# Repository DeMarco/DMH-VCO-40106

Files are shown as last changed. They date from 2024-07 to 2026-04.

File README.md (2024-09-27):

# DMH-VCO-40106
 VCO module based on the design by Moritz Klein around a CD40106 Hex Inverter chip.
 I've modified the circuit considerably, but the essence is still the same:
  - Better CV processing:
      - Frequency modulation can now be attenuated completely when the amount knob is all the way CCW
      - Added trimpots to allow for fine frequency knob range adjustment and centering on a specific note (inspired by LMNC Performance VCO)
      - Added normalled connection to receive note CV directly from the Troley Bus power system
      - Added extra FM CV input (wanted to make it Linear FM instead of exponential, but gave up tryin to figure it out)
      - All CV inputs are now behind two stages of OpAmp based inverting amplifiers before hitting the transistor pair
      - Added trimpots to adjust PW knob range and symmetry, and adapted resistors to accept 100k potentiometer
  - Sync input added (so that the oscillator can be hard-synced to another)
  - Triangle wave shaper added (took from Moritz Klein Wave Folder circuit)
  - Sine wave shaper added (Thomas Henry design)
  - Tuner added (inspired by LMNC Performance VCO), my own design and firmware running on an ATtiny4313 (not Arduino)

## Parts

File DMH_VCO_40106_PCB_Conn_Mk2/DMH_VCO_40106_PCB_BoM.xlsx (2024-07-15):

Reference | Value | Footprint | Qty
C1,C2,C9 | 47uF | Capacitor_THT:CP_Radial_D4.0mm_P2.00mm | 3
C3,C4,C5,C6,C7,C8,C14 | 100nF | Capacitor_THT:C_Disc_D4.3mm_W1.9mm_P5.00mm | 7
C10 | 2.2nF |  | 1
C11,C13 | 1uF |  | 2
C12 | 2.2uF |  | 1
D1 | 1N4148 | Diode_THT:D_DO-35_SOD27_P7.62mm_Horizontal | 1
J1 | Sync | SynthStuff:CUI_MJ-63052A | 1
J2 | V/Oct | SynthStuff:CUI_MJ-63052A | 1
J3 | Exp FM | SynthStuff:CUI_MJ-63052A | 1
J4 | Lin FM | SynthStuff:CUI_MJ-63052A | 1
J5 | PW Mod | SynthStuff:CUI_MJ-63052A | 1
J6 | Senoid | SynthStuff:CUI_MJ-63052A | 1
J7 | Triangle | SynthStuff:CUI_MJ-63052A | 1
J8 | Square | SynthStuff:CUI_MJ-63052A | 1
J9 | Sawtooth | SynthStuff:CUI_MJ-63052A | 1
J10 | Panel_GND | Connector_PinHeader_2.54mm:PinHeader_1x01_P2.54mm_Vertical | 1
J100 | IDC_02x08 | SynthStuff:IDC-Header_2x08_P2.54mm_Vertical_Eurorack | 1
Q1 | BC558 | Package_TO_SOT_THT:TO-92_Inline | 1
Q2,Q3,Q4 | BC548 | Package_TO_SOT_THT:TO-92_Inline | 3
Q5,Q6 | 2N3904 | Package_TO_SOT_THT:TO-92_Inline | 2
R1,R3,R4,R6,R7,R8,R9,R12,R13,R17,R18,R25,R26,R27,RV1,RV2,RV6,RV9 | 100k | -- mixed values -- | 18
R2 | 33k | Resistor_THT:R_Axial_DIN0204_L3.6mm_D1.6mm_P5.08mm_Horizontal | 1
R5,R11,RV3,RV4 | 1M | -- mixed values -- | 4
R10 | 1k5 | Resistor_THT:R_Axial_DIN0204_L3.6mm_D1.6mm_P5.08mm_Horizontal | 1
R14,R19 | 68k | Resistor_THT:R_Axial_DIN0204_L3.6mm_D1.6mm_P5.08mm_Horizontal | 2
R15 | 14k | Resistor_THT:R_Axial_DIN0204_L3.6mm_D1.6mm_P5.08mm_Horizontal | 1
R16 | 47k | Resistor_THT:R_Axial_DIN0204_L3.6mm_D1.6mm_P5.08mm_Horizontal | 1
R20,R21,R24,R28,RV5 | 1k | -- mixed values -- | 5
R22,R23,R33,R34,R35,R36,RV8,TH1,TH2,TH3,TH4,TH5,TH6 | 10k | -- mixed values -- | 13
R29,R32 | 2k2 |  | 2
R30 | 390 |  | 1
R31 | 18k |  | 1
RV7 | 250k | Potentiometer_THT:Potentiometer_Alpha_RD901F-40-00D_Single_Vertical | 1
RV10 | 50k |  | 1
TP1,TP2,TP3,TP4,TP5,TP6 | TestPoint |  | 6
U1 | 40106 | Package_DIP:DIP-14_W7.62mm_Socket | 1
U2 | TL074 | Package_DIP:DIP-14_W7.62mm_Socket | 1
U3 | TL072 | -- mixed values -- | 1
JFET | bs170
ATTiny85
thermistors | 100K
thermistors | 10K
regulator | 7805
regulator | 7905
sockets

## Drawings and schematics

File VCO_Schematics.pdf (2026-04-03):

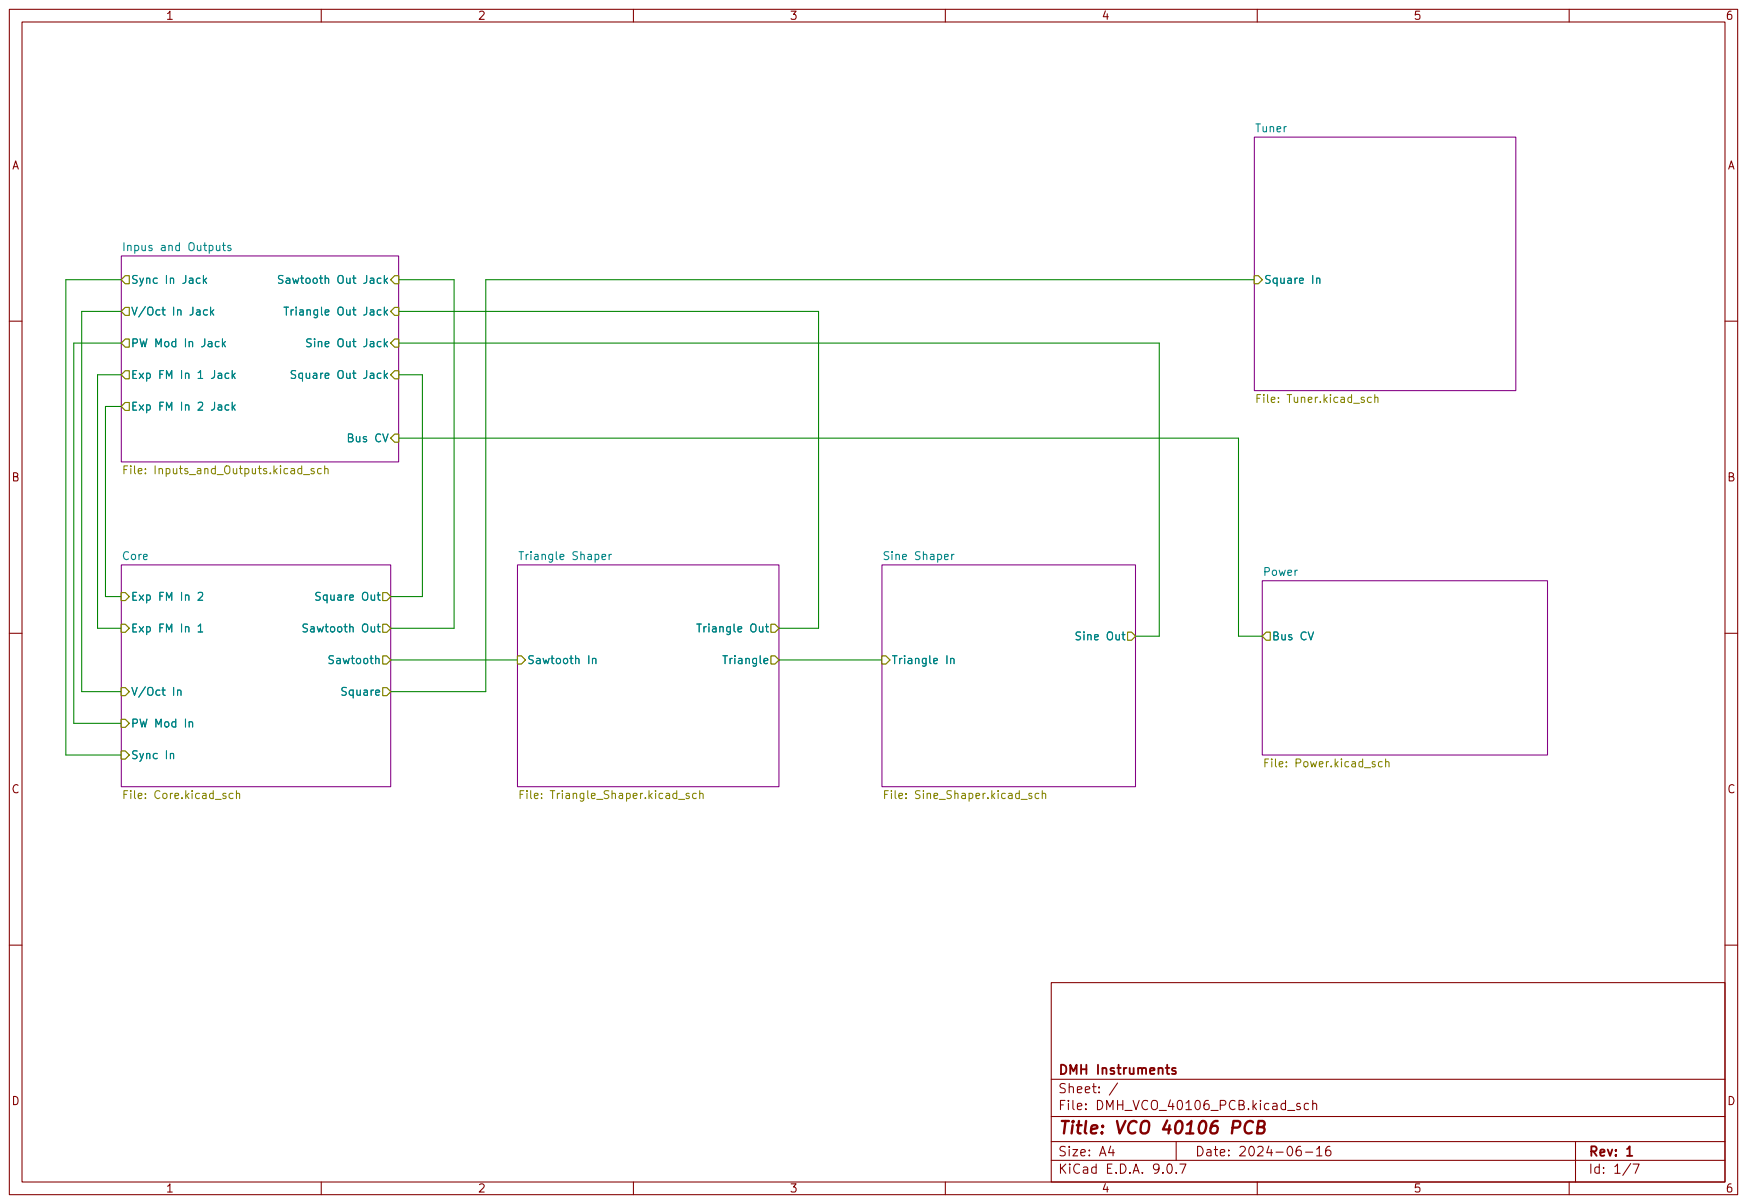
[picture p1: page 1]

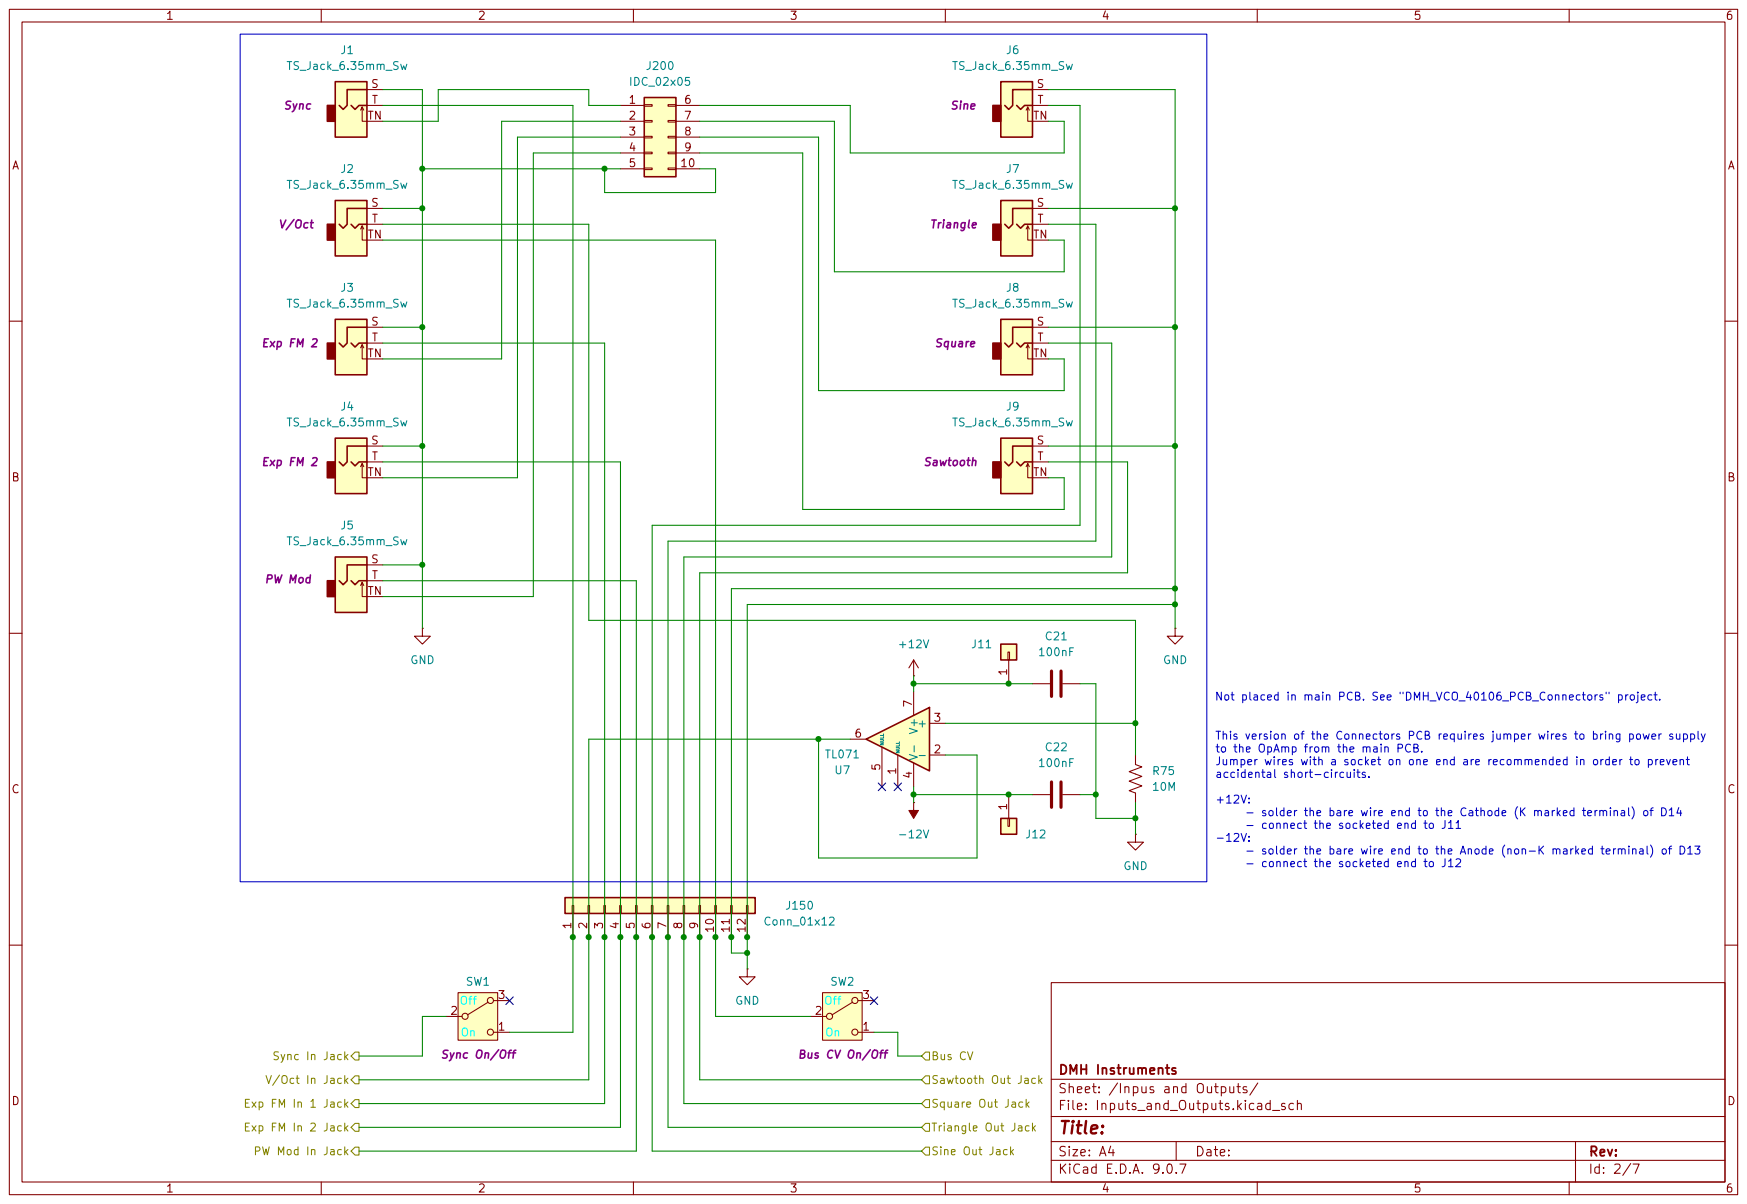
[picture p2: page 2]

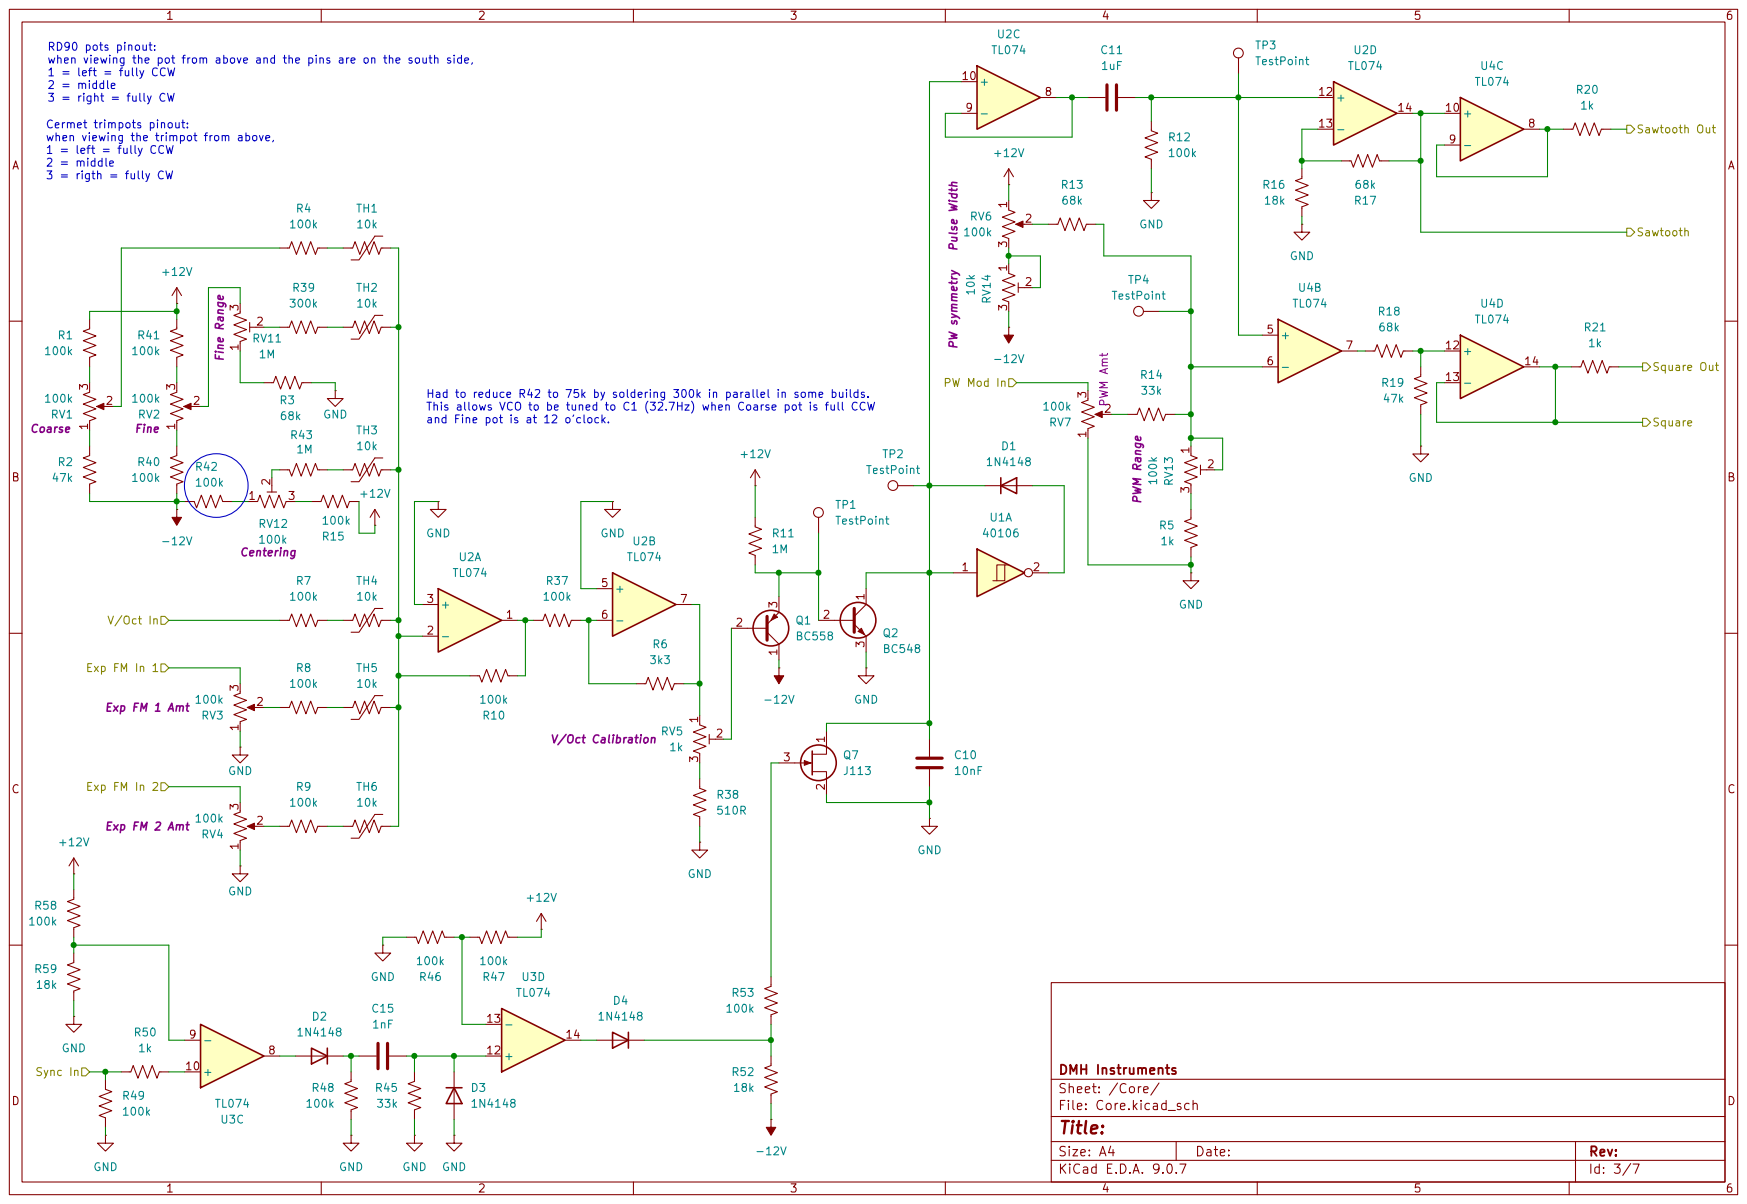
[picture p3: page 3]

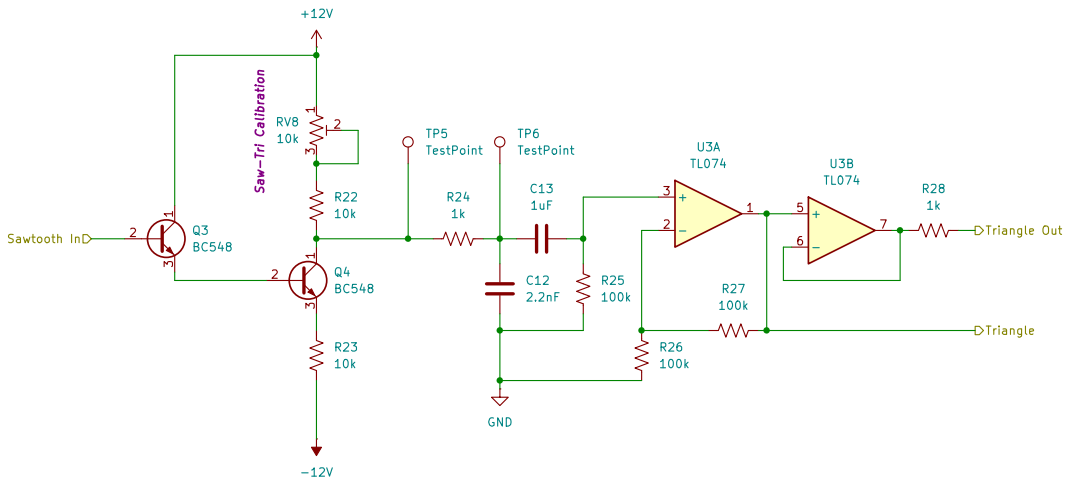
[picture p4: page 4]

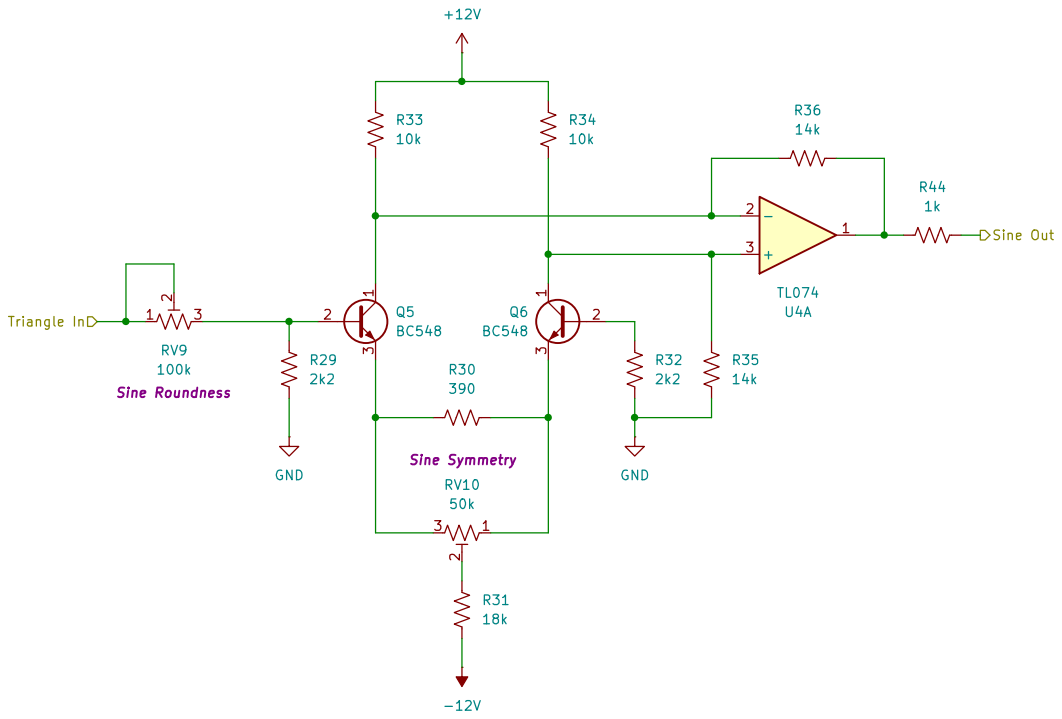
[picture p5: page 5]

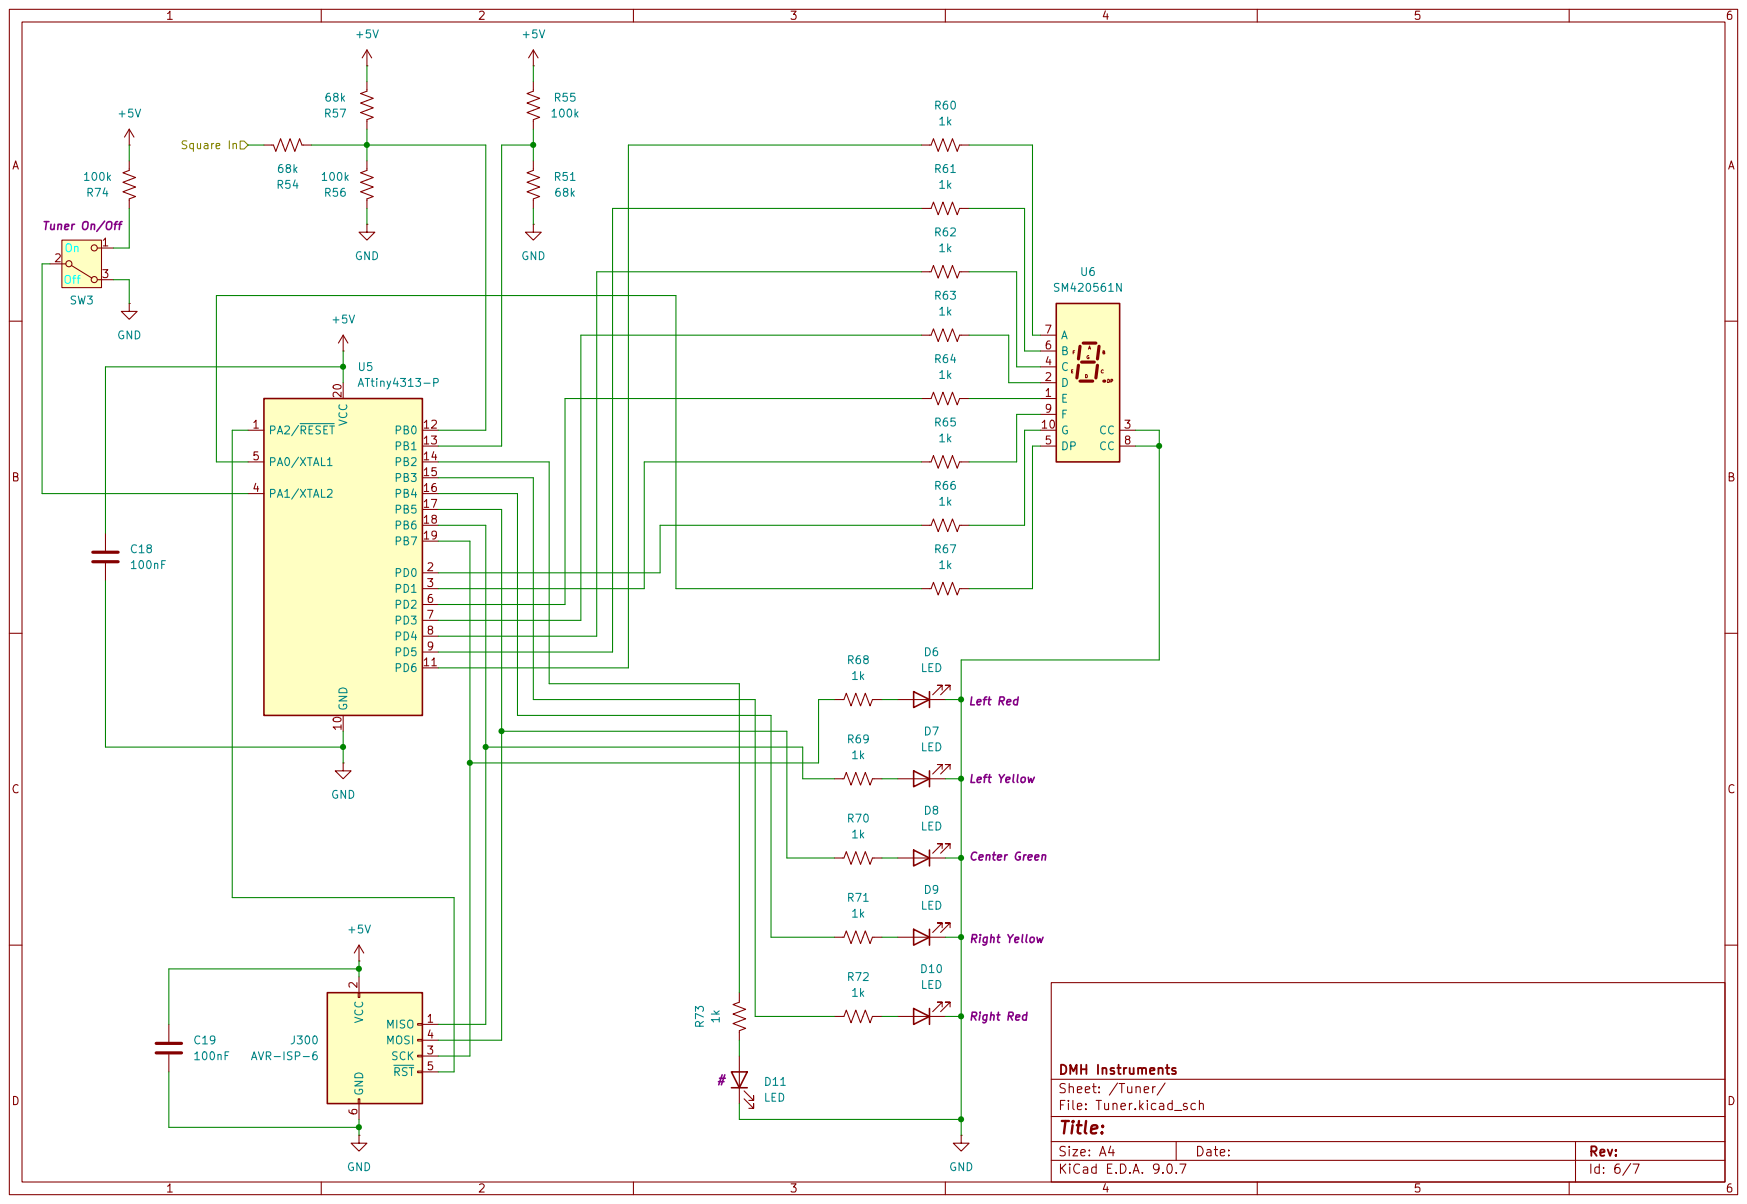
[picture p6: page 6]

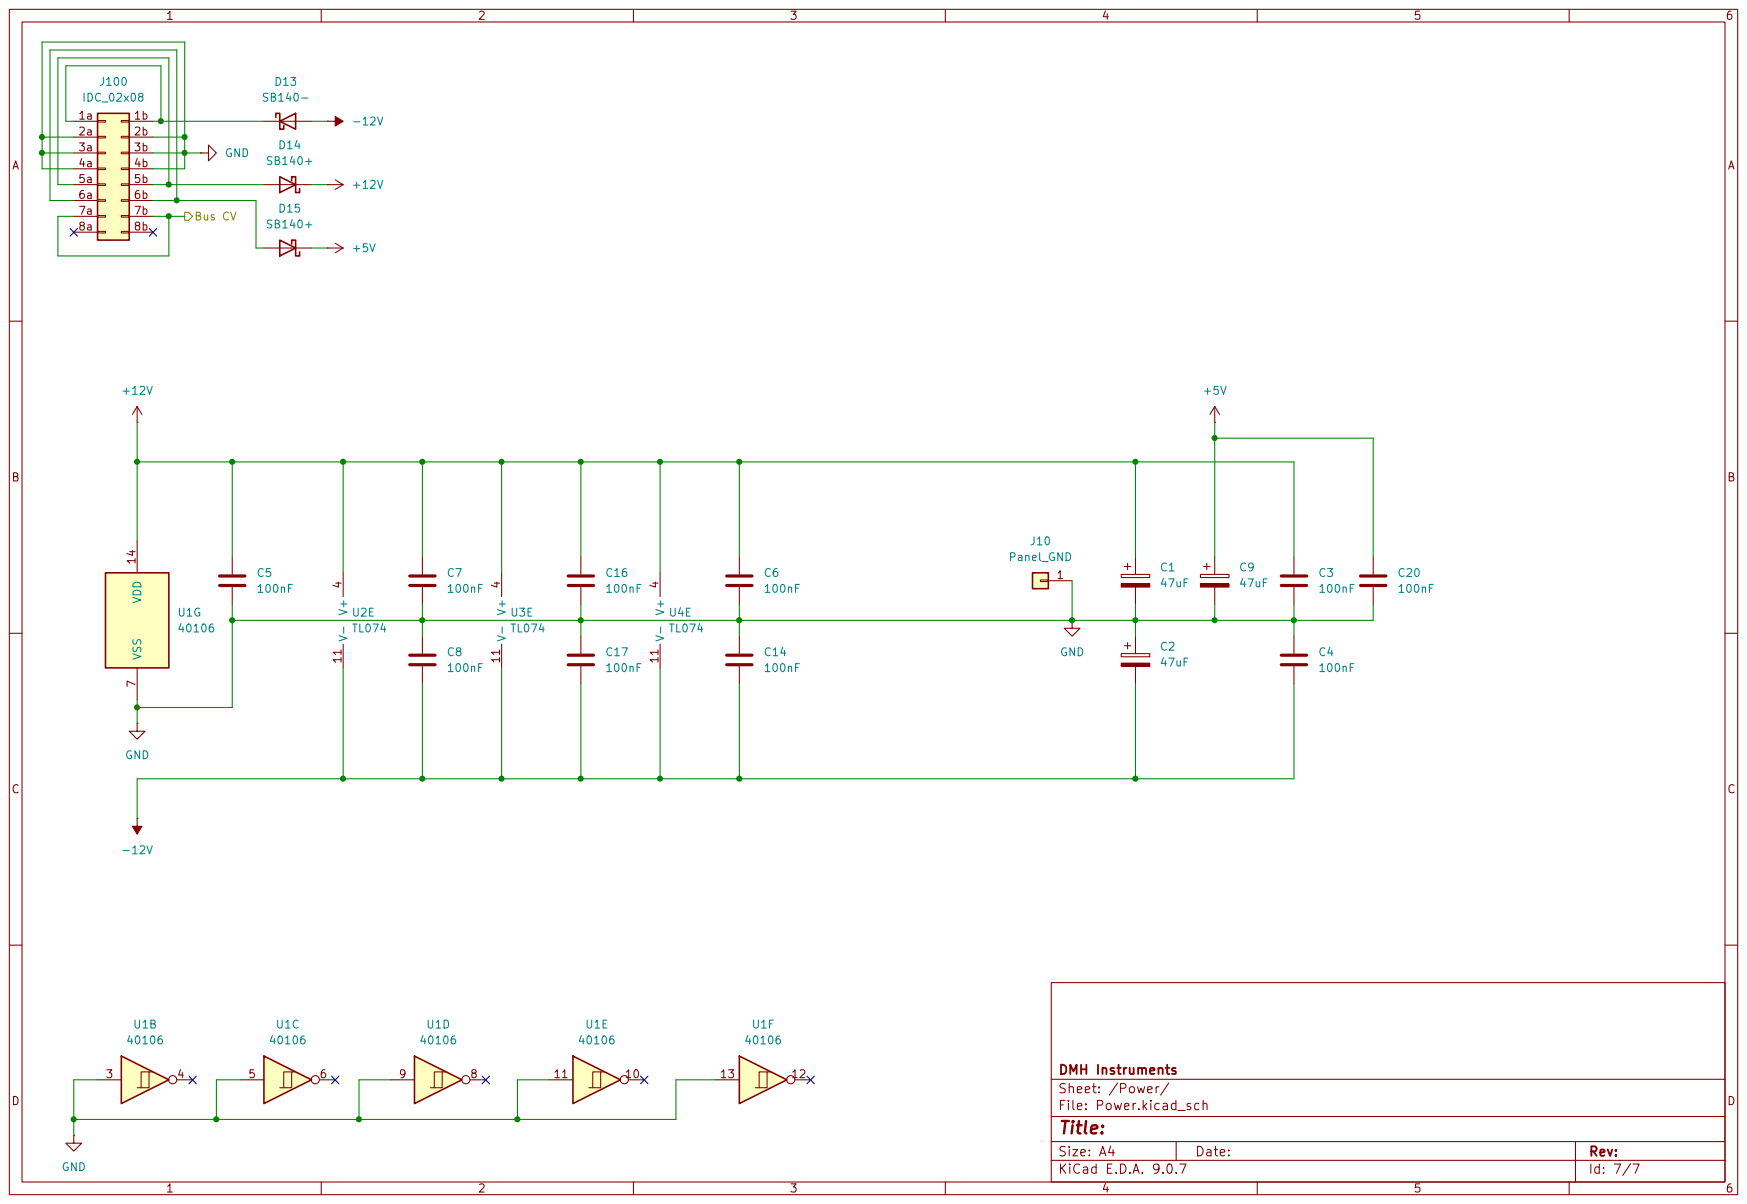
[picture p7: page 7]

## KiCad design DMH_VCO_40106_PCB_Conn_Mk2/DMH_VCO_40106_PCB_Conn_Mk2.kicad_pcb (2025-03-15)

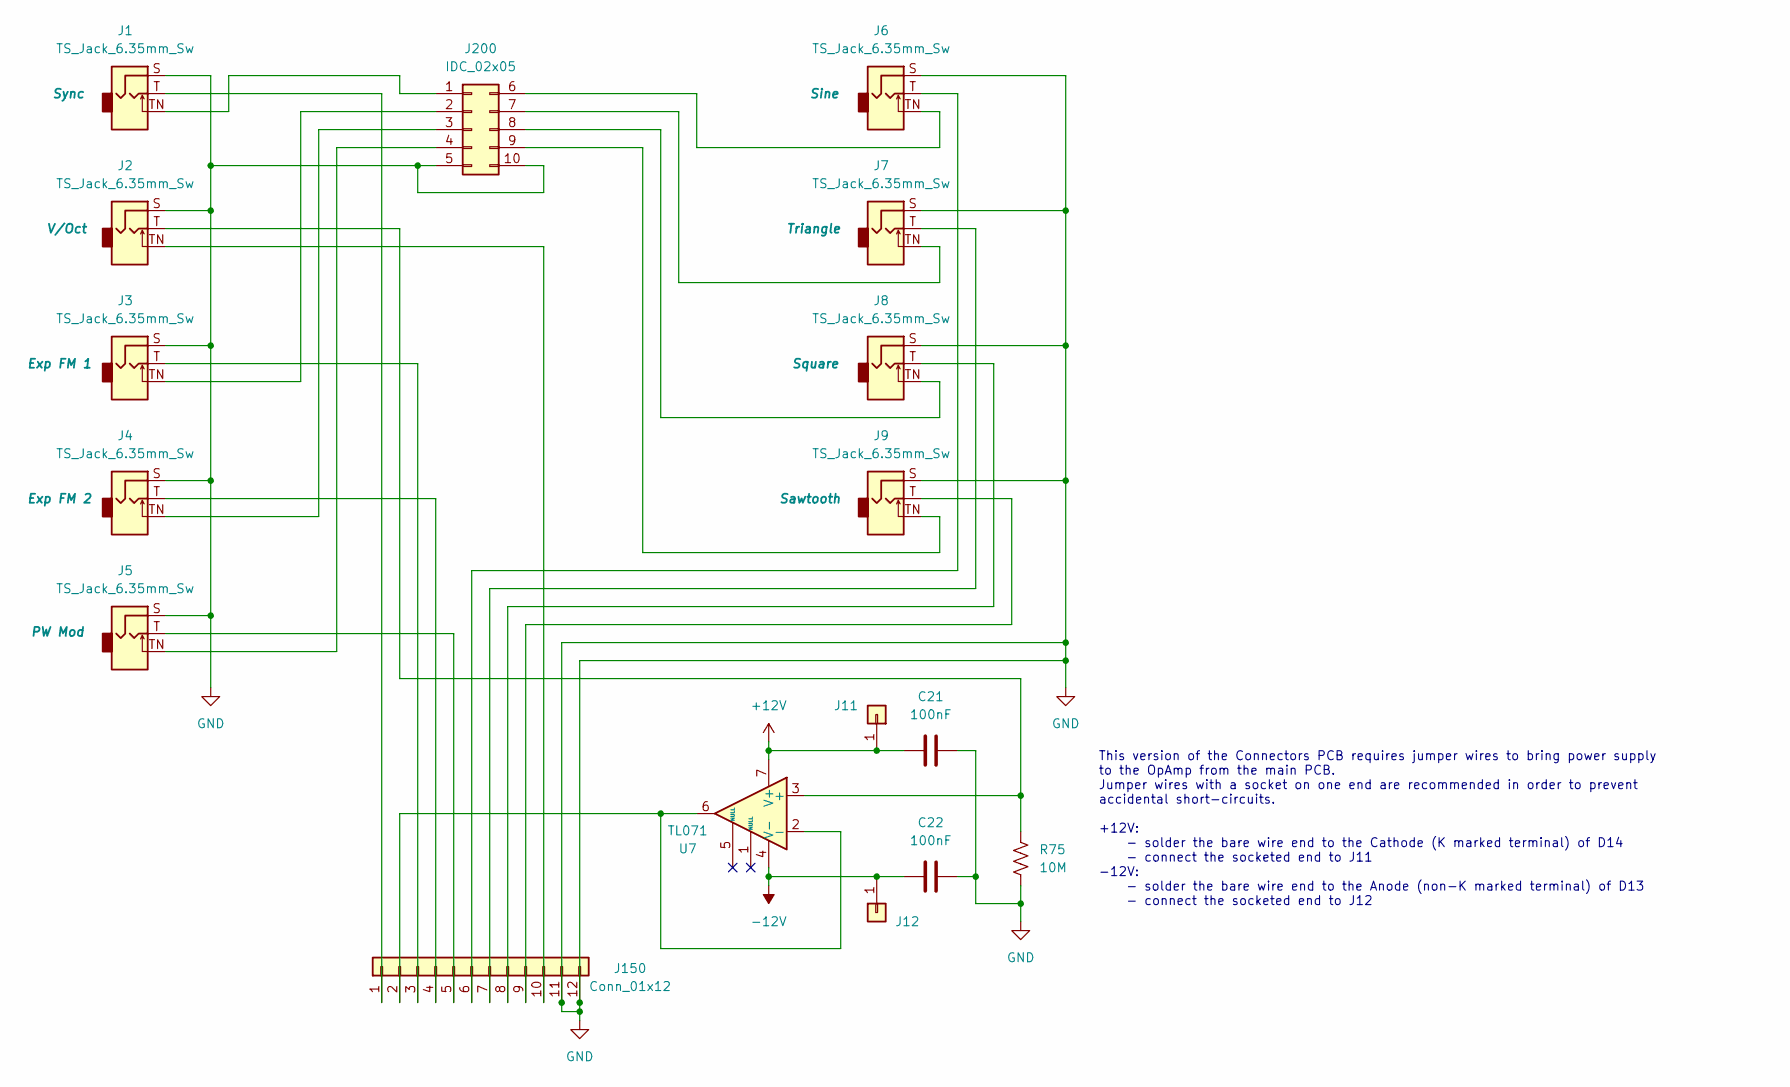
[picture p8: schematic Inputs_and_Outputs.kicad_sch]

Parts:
C21, C22: 100nF; C_Disc_D4.3mm_W1.9mm_P5.00mm
J1, J2, J3, J4, J5, J6, J7, J8, J9: TS_Jack_6.35mm_Sw; CUI_MJ-63052A
J11, J12: Conn_01x01; PinHeader_1x01_P2.54mm_Vertical
J150: Conn_01x12; PinHeader_1x12_P2.54mm_Vertical
J200: IDC_02x05; IDC-Header_2x05_P2.54mm_Vertical_BackBone
R75: 10M; R_Axial_DIN0207_L6.3mm_D2.5mm_P7.62mm_Horizontal
U7: TL071; DIP-8_W7.62mm_Socket

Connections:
+12V: C21.1, J11.1, U7.7 (V+)
-12V: C22.1, J12.1, U7.4 (V-)
GND: C21.2, C22.2, J1.S, J2.S, J3.S, J4.S, J5.S, J6.S, J7.S, J8.S, J9.S, J150.11, J150.12, J200.5, J200.10, R75.1
unnamed: J1.T, J150.1
unnamed: J150.2, U7.2 (-), U7.6
unnamed: J3.T, J150.3
unnamed: J4.T, J150.4
unnamed: J5.T, J150.5
unnamed: J6.T, J150.6
unnamed: J7.T, J150.7
unnamed: J8.T, J150.8
unnamed: J9.T, J150.9
unnamed: J2.TN, J150.10
unnamed: J1.TN, J200.1
unnamed: J3.TN, J200.2
unnamed: J4.TN, J200.3
unnamed: J5.TN, J200.4
unnamed: J6.TN, J200.6
unnamed: J7.TN, J200.7
unnamed: J8.TN, J200.8
unnamed: J9.TN, J200.9
unnamed: J2.T, R75.2, U7.3 (+)

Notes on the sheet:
This version of the Connectors PCB requires jumper wires to bring power supply to the OpAmp from the main PCB. Jumper wires with a socket on one end are recommended in order to prevent accidental short-circuits. +12V: - solder the bare wire end to the Cathode (K marked terminal) of D14 - connect th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

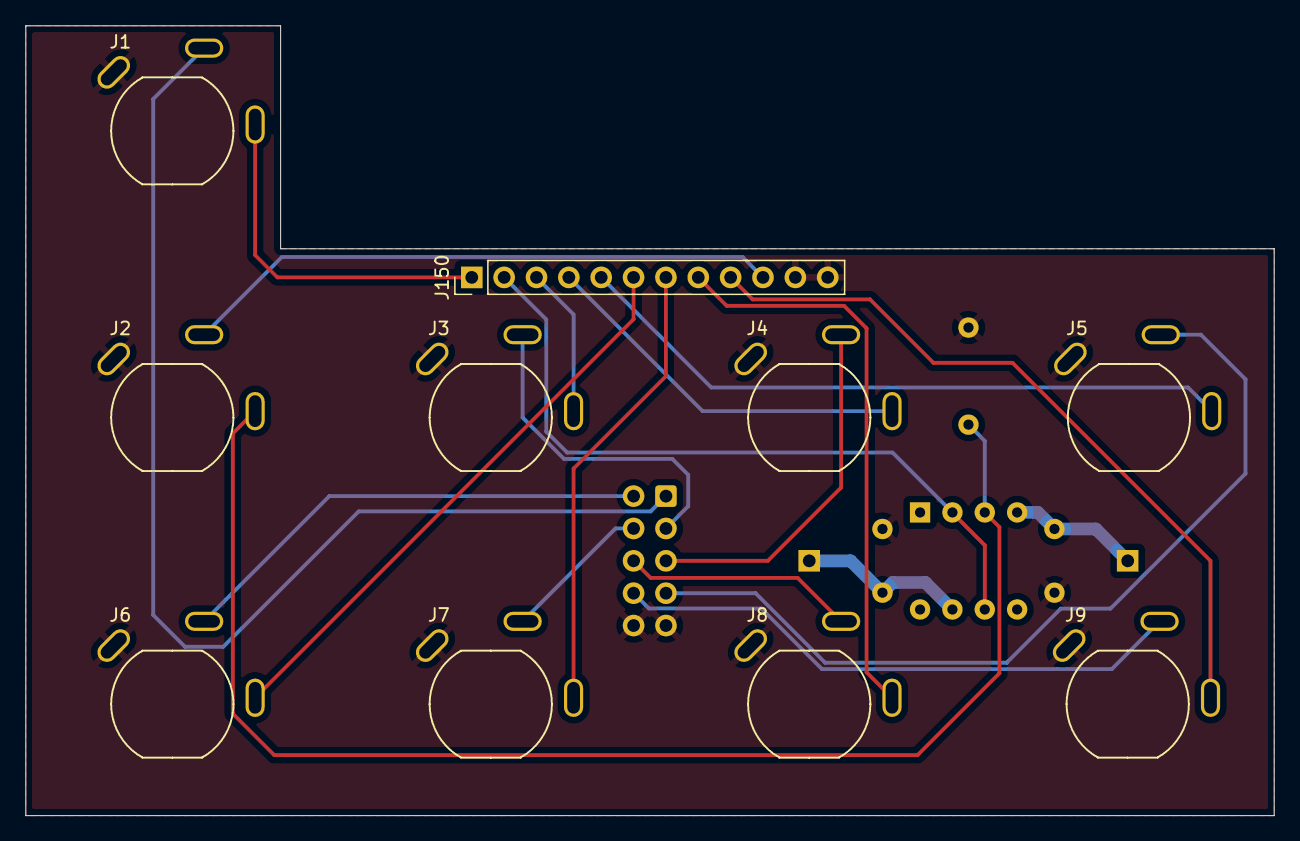
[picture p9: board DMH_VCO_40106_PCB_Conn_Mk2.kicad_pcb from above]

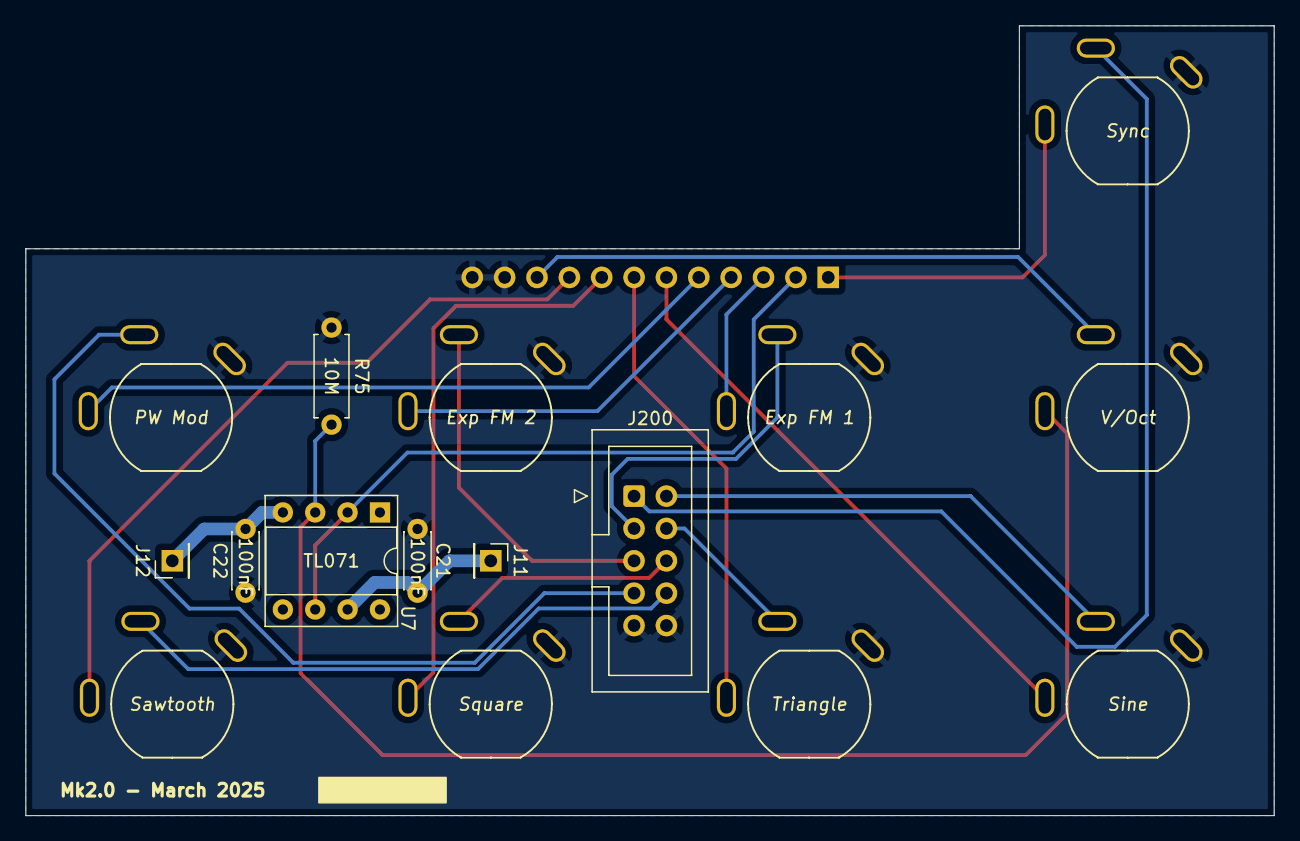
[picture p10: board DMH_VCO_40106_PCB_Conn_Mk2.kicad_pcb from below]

Board: 2 copper layers, 98.0 x 62.0 mm, 17 parts (7 on the bottom side), 22 nets.

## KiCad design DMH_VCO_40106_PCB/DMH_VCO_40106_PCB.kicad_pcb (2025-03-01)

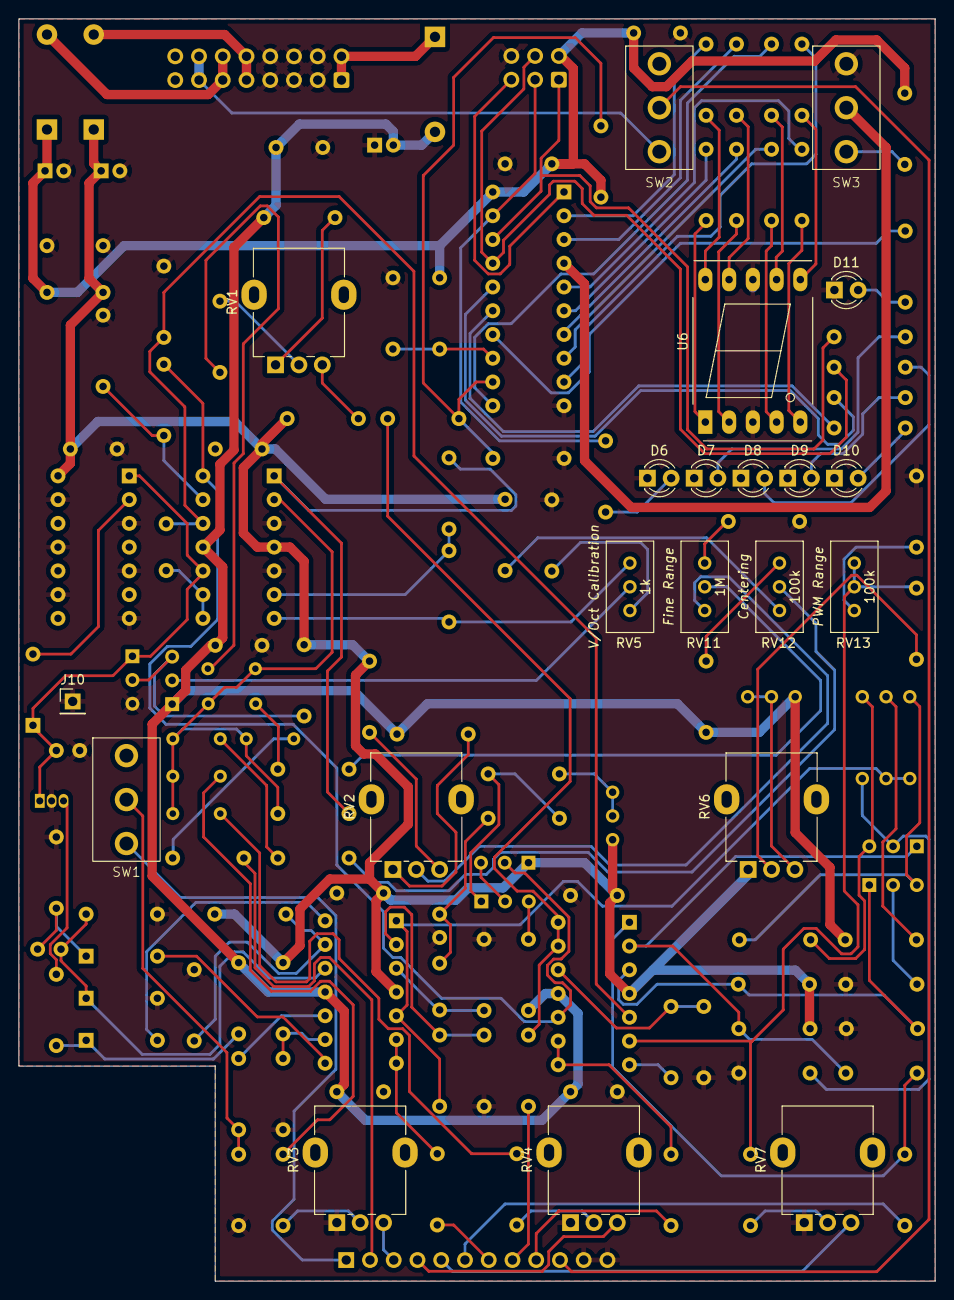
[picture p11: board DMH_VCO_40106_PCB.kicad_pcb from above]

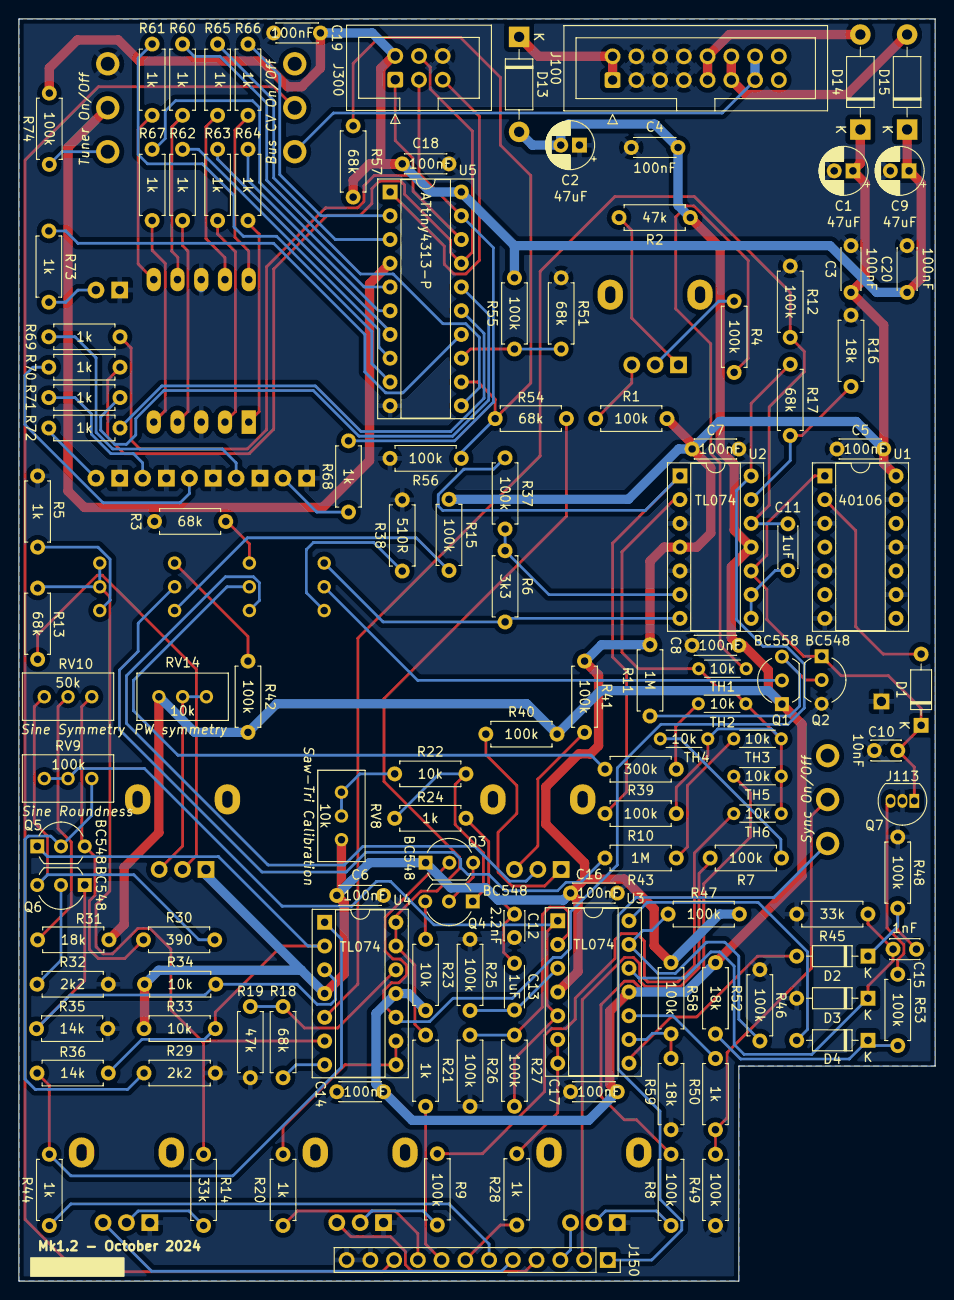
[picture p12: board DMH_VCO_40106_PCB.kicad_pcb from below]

Board: 2 copper layers, 98.0 x 135.0 mm, 147 parts (126 on the bottom side), 119 nets.

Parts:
C1, C2, C9: 47uF; CP_Radial_D5.0mm_P2.00mm
C3, C4, C5, C6, C7, C8, C14, C16, C17, C18, C19, C20: 100nF; C_Disc_D4.3mm_W1.9mm_P5.00mm
C10: 10nF; C_Disc_D3.0mm_W2.0mm_P2.50mm
C11, C13: 1uF; C_Disc_D4.3mm_W1.9mm_P5.00mm
C12: 2.2nF; C_Disc_D3.0mm_W2.0mm_P2.50mm
C15: 1nF; C_Disc_D3.0mm_W2.0mm_P2.50mm
D1, D2, D3, D4: 1N4148; D_DO-35_SOD27_P7.62mm_Horizontal
D6, D7, D8, D9, D10, D11: LED; LED_D3.0mm
D13: SB140-; D_DO-41_SOD81_P10.16mm_Horizontal
D14, D15: SB140+; D_DO-41_SOD81_P10.16mm_Horizontal
J10: Panel_GND; PinHeader_1x01_P2.54mm_Vertical
J100: IDC_02x08; IDC-Header_2x08_P2.54mm_Vertical_Eurorack
J150: Conn_01x12; PinSocket_1x12_P2.54mm_Vertical
J300: AVR-ISP-6; IDC-Header_2x03_P2.54mm_Vertical
Q1: BC558; TO-92_Inline_Wide
Q2, Q3, Q4, Q5, Q6: BC548; TO-92_Inline_Wide
Q7: J113; TO-92_Inline
R1, R4, R7, R8, R9, R10, R12, R15, R25, R26, R27, R37, R40, R41, R42, R46, R47, R48, R49, R53, R55, R56, R58, R74: 100k; R_Axial_DIN0207_L6.3mm_D2.5mm_P7.62mm_Horizontal
R2, R19: 47k; R_Axial_DIN0207_L6.3mm_D2.5mm_P7.62mm_Horizontal
R3, R13, R17, R18, R51, R54, R57: 68k; R_Axial_DIN0207_L6.3mm_D2.5mm_P7.62mm_Horizontal
R5, R20, R21, R24, R28, R44, R50, R60, R61, R62, R63, R64, R65, R66, R67, R68, R69, R70, R71, R72, R73: 1k; R_Axial_DIN0207_L6.3mm_D2.5mm_P7.62mm_Horizontal
R6: 3k3; R_Axial_DIN0207_L6.3mm_D2.5mm_P7.62mm_Horizontal
R11, R43: 1M; R_Axial_DIN0207_L6.3mm_D2.5mm_P7.62mm_Horizontal
R14, R45: 33k; R_Axial_DIN0207_L6.3mm_D2.5mm_P7.62mm_Horizontal
R16, R31, R52, R59: 18k; R_Axial_DIN0207_L6.3mm_D2.5mm_P7.62mm_Horizontal
R22, R23, R33, R34: 10k; R_Axial_DIN0207_L6.3mm_D2.5mm_P7.62mm_Horizontal
R29, R32: 2k2; R_Axial_DIN0207_L6.3mm_D2.5mm_P7.62mm_Horizontal
R30: 390; R_Axial_DIN0207_L6.3mm_D2.5mm_P7.62mm_Horizontal
R35, R36: 14k; R_Axial_DIN0207_L6.3mm_D2.5mm_P7.62mm_Horizontal
R38: 510R; R_Axial_DIN0207_L6.3mm_D2.5mm_P7.62mm_Horizontal
R39: 300k; R_Axial_DIN0207_L6.3mm_D2.5mm_P7.62mm_Horizontal
RV1, RV2, RV3, RV4, RV6, RV7: 100k; Potentiometer_Alpha_RD901F-40-00D_Single_Vertical
RV5: 1k; Potentiometer_Bourns_3296W_Vertical
RV8, RV14: 10k; Potentiometer_Bourns_3296W_Vertical
RV9, RV12, RV13: 100k; Potentiometer_Bourns_3296W_Vertical
RV10: 50k; Potentiometer_Bourns_3296W_Vertical
RV11: 1M; Potentiometer_Bourns_3296W_Vertical
SW1, SW2, SW3: SW_SPDT_321_OnOff; Toggle_Switch_THT
TH1, TH2, TH3, TH4, TH5, TH6: 10k; R_Axial_DIN0204_L3.6mm_D1.6mm_P5.08mm_Horizontal
U1: 40106; DIP-14_W7.62mm_Socket
U2, U3, U4: TL074; DIP-14_W7.62mm_Socket
U5: ATtiny4313-P; DIP-20_W7.62mm_Socket
U6: SM420561N; 7SegmentLED_LTS6760_LTS6780

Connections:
+5V: C9.1, C18.1, C19.1, C20.1, D15.1 (K), J300.2 (VCC), R55.2, R57.1, R74.1, U5.20 (VCC)
+12V: C1.1, C3.1, C5.1, C6.1, C7.1, C16.1, D14.1 (K), Q3.1 (C), R1.2, R11.2, R15.1, R33.1, R34.1, R41.1, R47.2, R58.1, RV6.1, RV8.1, U1.14 (VDD), U2.4 (V+), U3.4 (V+), U4.4 (V+)
-12V: C2.2, C4.2, C8.2, C14.2, C17.2, D13.2 (A), Q1.1 (C), R2.1, R23.2, R31.1, R40.2, R42.2, R52.2, RV14.3, U2.11 (V-), U3.11 (V-), U4.11 (V-)
/Core/Exp FM In 1: J150.3, RV3.3
/Core/Exp FM In 2: J150.4, RV4.3
/Core/PW Mod In: J150.5, RV7.3
/Core/Sawtooth: Q3.2 (B), R17.1, U2.14, U4.10 (+)
/Core/Sawtooth Out: J150.9, R20.2
/Core/Square: R21.1, R54.1, U4.13 (-), U4.14
/Core/Square Out: J150.8, R21.2
/Core/Sync In: R49.2, R50.2, SW1.2 (B)
/Core/V/Oct In: J150.2, R7.2
/Inpus and Outputs/Bus CV: J100.7a, J100.7b, SW2.1 (C)
/Inpus and Outputs/Sine Out Jack: J150.6, R44.1
/Inpus and Outputs/Triangle Out Jack: J150.7, R28.1
/Sine Shaper/Triangle In: R27.2, RV9.1, RV9.2, U3.1, U3.5 (+)
GND: C1.2, C2.1, C3.2, C4.1, C5.2, C6.2, C7.2, C8.1, C9.2, C10.2, C12.1, C14.1, C16.2, C17.1, C18.2, C19.2, C20.2, D3.2 (A), D6.1 (K), D7.1 (K), D8.1 (K), D9.1 (K), D10.1 (K), D11.1 (K), J10.1, J100.2a, J100.2b, J100.3a, J100.3b, J100.4a, J100.4b, J150.11, J150.12, J300.6 (GND), Q2.3 (E), Q7.2 (S), R3.1, R5.2, R12.1, R16.1, R19.2, R25.2, R26.2, R29.2, R32.2, R35.2, R38.2, R45.2, R46.1, R48.2, R49.1, R51.1, R56.2, R59.2, RV3.1, RV4.1, RV7.1, SW3.3 (A), U1.3, U1.5, U1.7 (VSS), U1.9, U1.11, U1.13, U2.3 (+), U2.5 (+), U5.10 (GND), U6.3 (CC), U6.8 (CC)
unnamed: C12.2, C13.1, R24.2
unnamed: D1.2 (A), U1.2
unnamed: C10.1, D1.1 (K), Q2.1 (C), Q7.1 (D), U1.1, U2.10 (+)
unnamed: D2.2 (A), U3.8
unnamed: C15.1, D2.1 (K), R48.1
unnamed: C15.2, D3.1 (K), R45.1, U3.12 (+)
unnamed: D4.2 (A), U3.14
unnamed: D4.1 (K), R52.1, R53.2
unnamed: D6.2 (A), R68.2
unnamed: D7.2 (A), R69.2
unnamed: D8.2 (A), R70.2
unnamed: D9.2 (A), R71.2
unnamed: D10.2 (A), R72.2
unnamed: D11.2 (A), R73.2
unnamed: D13.1 (K), J100.1a, J100.1b
unnamed: D14.2 (A), J100.5a, J100.5b
unnamed: D15.2 (A), J100.6a, J100.6b
unnamed: J150.1, SW1.1 (C)
unnamed: J150.10, SW2.2 (B)
unnamed: J300.1 (MISO), R69.1, U5.18 (PB6)
unnamed: J300.4 (MOSI), R70.1, U5.17 (PB5)
unnamed: J300.3 (SCK), R68.1, U5.19 (PB7)
unnamed: J300.5 (~RST), U5.1 (PA2/~RESET)
unnamed: Q1.2 (B), RV5.2
unnamed: Q1.3 (E), Q2.2 (B), R11.1
unnamed: Q3.3 (E), Q4.2 (B)
unnamed: Q4.1 (C), R22.2, R24.1
unnamed: Q4.3 (E), R23.1
unnamed: Q5.2 (B), R29.1, RV9.3
unnamed: Q5.1 (C), R33.2, R36.1, U4.2 (-)
unnamed: Q5.3 (E), R30.1, RV10.3
unnamed: Q6.2 (B), R32.1
unnamed: Q6.1 (C), R34.2, R35.1, U4.3 (+)
unnamed: Q6.3 (E), R30.2, RV10.1
unnamed: Q7.3 (G), R53.1
unnamed: R1.1, RV1.3
unnamed: R2.2, RV1.1
unnamed: R3.2, RV11.1
unnamed: R4.1, RV1.2
unnamed: R4.2, TH1.1
unnamed: R5.1, RV13.3
unnamed: R6.2, RV5.1, U2.7
unnamed: R7.1, TH4.1
unnamed: R8.1, RV3.2
unnamed: R8.2, TH5.1
unnamed: R9.1, RV4.2
unnamed: R9.2, TH6.1
unnamed: R10.2, R37.1, U2.1
unnamed: R13.2, RV6.2
unnamed: R14.2, RV7.2
unnamed: R15.2, RV12.3
unnamed: R18.2, U4.7
unnamed: R22.1, RV8.2, RV8.3
unnamed: R31.2, RV10.2
unnamed: R36.2, R44.2, U4.1
unnamed: R38.1, RV5.3
unnamed: R39.1, RV11.2
unnamed: R39.2, TH2.1
unnamed: R40.1, RV2.1
unnamed: R41.2, RV2.3
unnamed: R42.1, RV12.1
unnamed: R43.1, TH3.1
unnamed: R43.2, RV12.2
unnamed: RV2.2, RV11.3
unnamed: RV6.3, RV14.1, RV14.2
unnamed: SW3.2 (B), U5.4 (PA1/XTAL2)
unnamed: R74.2, SW3.1 (C)
unnamed: R10.1, TH1.2, TH2.2, TH3.2, TH4.2, TH5.2, TH6.2, U2.2 (-)
unnamed: R6.1, R37.2, U2.6 (-)
unnamed: C11.1, U2.8, U2.9 (-)
unnamed: C11.2, R12.2, U2.12 (+), U4.5 (+)
unnamed: R16.2, R17.2, U2.13 (-)
unnamed: C13.2, R25.1, U3.3 (+)
unnamed: R26.1, R27.1, U3.2 (-)
unnamed: R28.2, U3.6 (-), U3.7
unnamed: R50.1, U3.10 (+)
unnamed: R58.2, R59.1, U3.9 (-)
unnamed: R46.2, R47.1, U3.13 (-)
unnamed: R13.1, R14.1, RV13.1, RV13.2, U4.6 (-)
unnamed: R20.1, U4.8, U4.9 (-)
unnamed: R18.1, R19.1, U4.12 (+)
unnamed: R67.1, U5.5 (PA0/XTAL1)
unnamed: R54.2, R56.1, R57.2, U5.12 (PB0)
unnamed: R51.2, R55.1, U5.13 (PB1)
unnamed: R73.1, U5.14 (PB2)
unnamed: R72.1, U5.15 (PB3)
unnamed: R71.1, U5.16 (PB4)
unnamed: R66.1, U5.2 (PD0)
unnamed: R65.1, U5.3 (PD1)
unnamed: R64.1, U5.6 (PD2)
unnamed: R63.1, U5.7 (PD3)
unnamed: R62.1, U5.8 (PD4)
unnamed: R61.1, U5.9 (PD5)
unnamed: R60.1, U5.11 (PD6)
unnamed: R60.2, U6.7 (A)
unnamed: R61.2, U6.6 (B)
unnamed: R62.2, U6.4 (C)
unnamed: R63.2, U6.2 (D)
unnamed: R67.2, U6.5 (DP)
unnamed: R64.2, U6.1 (E)
unnamed: R65.2, U6.9 (F)
unnamed: R66.2, U6.10 (G)

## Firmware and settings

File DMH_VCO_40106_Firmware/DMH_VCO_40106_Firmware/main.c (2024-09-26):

/*
 * DMH_VCO_40106_Firmware.c
 *
 * Created: 25/08/2024 20:57:13
 * Author : Draycon
 */ 

#include "definitions.h"
#include <inttypes.h>
#include <stdio.h>
#include <stdlib.h>
#include <avr/io.h>
#include <avr/interrupt.h>
#include <avr/pgmspace.h>
#include <util/delay.h>
#include <avr/eeprom.h>
#include "Frequency_table_float.h"

//////// GLOBAL VARIABLES ////////

uint16_t event_timestamp = 0;


/////// FUNCTIONS /////////

/*
Show that the 7 segments display and LEDs are all working at power up.
*/
void init_display (void)
{
	// Switch off all segments
	PORTA &= ~_BV(SEG_DP);
	ALL_SEGS_OFF();
	
	// Light up all segments and LEDs in order
	_delay_ms(150);
	PORTD |= _BV(SEG_F);
	_delay_ms(150);
	PORTD |= _BV(SEG_A);
	_delay_ms(150);
	PORTD |= _BV(SEG_B);
	_delay_ms(150);
	PORTD |= _BV(SEG_C);
	_delay_ms(150);
	PORTD |= _BV(SEG_D);
	_delay_ms(150);
	PORTD |= _BV(SEG_E);
	_delay_ms(150);
	PORTD |= _BV(SEG_G);
	_delay_ms(150);
	PORTA |= _BV(SEG_DP);
	_delay_ms(150);
	LED_Sharp_ON();
	_delay_ms(150);
	LED_L_Red_ON();
	_delay_ms(150);
	LED_L_Yellow_ON();
	_delay_ms(150);
	LED_C_Green_ON();
	_delay_ms(150);
	LED_R_Yellow_ON();
	_delay_ms(150);
	LED_R_Red_ON();
	_delay_ms(1000);
	// Switch off all segments
	ALL_SEGS_OFF();
	// Switch off all LEDs
	ALL_LEDS_OFF();
}

/*
Light up the 7 segments display and "sharp" LED according to the calculated note.
*/
void display_note (uint8_t note)
{
	switch(note)
	{
		case NOTE_C:
			//PORTD = _BV(SEG_A) | _BV(SEG_D) | _BV(SEG_E) | _BV(SEG_F) & ~_BV(SEG_B) & ~_BV(SEG_C) & ~_BV(SEG_G);
			PORTD = 0x4E;
			LED_Sharp_OFF();
			break;
			
		case NOTE_Cs:
			//PORTD = _BV(SEG_A) | _BV(SEG_D) | _BV(SEG_E) | _BV(SEG_F) & ~_BV(SEG_B) & ~_BV(SEG_C) & ~_BV(SEG_G);
			PORTD = 0x4E;
			LED_Sharp_ON();
			break;
			
		case NOTE_D:
			//PORTD = _BV(SEG_B) | _BV(SEG_C) | _BV(SEG_D) | _BV(SEG_E) | _BV(SEG_G) & ~_BV(SEG_A) & ~_BV(SEG_F);
			PORTD = 0x3D;
			LED_Sharp_OFF();
			break;
			
		case NOTE_Ds:
			//PORTD = _BV(SEG_B) | _BV(SEG_C) | _BV(SEG_D) | _BV(SEG_E) | _BV(SEG_G) & ~_BV(SEG_A) & ~_BV(SEG_F);
			PORTD = 0x3D;
			LED_Sharp_ON();
			break;
			
		case NOTE_E:
			//PORTD = _BV(SEG_A) | _BV(SEG_D) | _BV(SEG_E) | _BV(SEG_F) | _BV(SEG_G) & ~_BV(SEG_B) & ~_BV(SEG_C);
			PORTD = 0x4F;
			LED_Sharp_OFF();
			break;
		
		case NOTE_F:
			//PORTD = _BV(SEG_A) | _BV(SEG_E) | _BV(SEG_F) | _BV(SEG_G) & ~_BV(SEG_B) & ~_BV(SEG_C) & ~_BV(SEG_D);
			PORTD = 0x47;
			LED_Sharp_OFF();
			break;
			
		case NOTE_Fs:
			//PORTD = _BV(SEG_A) | _BV(SEG_E) | _BV(SEG_F) | _BV(SEG_G) & ~_BV(SEG_B) & ~_BV(SEG_C) & ~_BV(SEG_D);
			PORTD = 0x47;
			LED_Sharp_ON();
			break;
				
		case NOTE_G:
			//PORTD = _BV(SEG_A) | _BV(SEG_C) | _BV(SEG_D) | _BV(SEG_E) | _BV(SEG_F) & ~_BV(SEG_G) & ~_BV(SEG_B);
			PORTD = 0x5E;
			LED_Sharp_OFF();
			break;
			
		case NOTE_Gs:
			//PORTD = _BV(SEG_A) | _BV(SEG_C) | _BV(SEG_D) | _BV(SEG_E) | _BV(SEG_F) & ~_BV(SEG_G) & ~_BV(SEG_B);
			PORTD = 0x5E;
			LED_Sharp_ON();
			break;
			
		case NOTE_A:
			//PORTD = _BV(SEG_A) | _BV(SEG_B) | _BV(SEG_C) | _BV(SEG_E) | _BV(SEG_F) | _BV(SEG_G) & ~_BV(SEG_D);
			PORTD = 0x77;
			LED_Sharp_OFF();
			break;
			
		case NOTE_As:
			//PORTD = _BV(SEG_A) | _BV(SEG_B) | _BV(SEG_C) | _BV(SEG_E) | _BV(SEG_F) | _BV(SEG_G) & ~_BV(SEG_D);
			PORTD = 0x77;
			LED_Sharp_ON();
			break;
			
		case NOTE_B:
			//PORTD = _BV(SEG_C) | _BV(SEG_D) | _BV(SEG_E) | _BV(SEG_F) | _BV(SEG_G) & ~_BV(SEG_A) & ~_BV(SEG_B);
			PORTD = 0x1F;
			LED_Sharp_OFF();
			break;
			
		case NOTE_TOO_LOW:
			// Seg D only
			PORTD = 0x08;
			LED_Sharp_OFF();
			break;
		
		case NOTE_TOO_HIGH:
			// Seg A only
			PORTD = 0x40;
			LED_Sharp_OFF();
			break;
		
		default:
			// Seg A and B, diagnostic purposes only
			PORTD = 0x48;
			LED_Sharp_OFF();
			break;
	}
	
}

/*
Calculate Note based on Timer1 "timestamp",
which is just the number of microseconds
counted by Timer1 until a new wave cycle is detected.
*/
void calculate_note (uint16_t timestamp)
{
	float freq = 0.0;
	float period_us = 0.0;
	uint8_t i, accu, note;
	
	// Convert timestamp into period in microseconds (so divide timestamp by 1 million)
	period_us = timestamp / 1000.0;
	period_us = period_us / 1000.0;
	
	// Convert period (in microseconds) into frequency (in Hertz)
	freq = 1.0 / period_us;
	
	// Check if frequency is within usable range
	if(freq < pgm_read_float(&frequency_table[NOTE_MIN][0]))
	{
		display_note(NOTE_TOO_LOW);
		ALL_LEDS_OFF();
		return;
	}
	else if(freq >= pgm_read_float(&frequency_table[NOTE_MAX][0]))
	{
		display_note(NOTE_TOO_HIGH);
		ALL_LEDS_OFF();
		return;
	}
	
	// Check which octave the frequency belongs to
	i = 1;
	while(!(((freq >= pgm_read_float(&frequency_table[i][0]))) && (freq < pgm_read_float(&frequency_table[i+12][0]))))
	{
		// If freq is not within this octave, go to the next octave
		i+=12; 
	}
	
	// Check which note band the frequency belongs to
	note = 1;
	while(!(((freq >= pgm_read_float(&frequency_table[i][0]))) && (freq < pgm_read_float(&frequency_table[i+1][0]))))
	{
		// If freq is not within this note band, go to next note
		i++;
		note++;
	}
	
	// Check which note accuracy the frequency belongs to
	accu = 0;
	while(!(((freq >= pgm_read_float(&frequency_table[i][accu]))) && (freq < pgm_read_float(&frequency_table[i][accu+1]))))
	{
		// If not within this accuracy band, go to next accuracy band
		accu++;
		if(accu==4)
			break;
	}

	// Display note and accuracy LED
	display_note(note);
	ALL_ACCURACY_LEDS_OFF();	
	switch(accu)
	{
		case 0:
			LED_L_Red_ON();
			break;
		case 1:
			LED_L_Yellow_ON();
			break;
		case 2:
			LED_C_Green_ON();
			break;
		case 3:
			LED_R_Yellow_ON();
			break;
		case 4:
			LED_R_Red_ON();
			break;
		// For diagnostics purpose only:
		default:
			ALL_ACCURACY_LEDS_ON();
			break;			
	}
}

/*
Configure IO pins function and direction.
Configure Analog Comparator.
Configure Timer0 and Timer1.
*/
void ioinit (void)
{
	// Better calibrate internal 8 MHz RC Oscillator with user value stored in EEPROM
	uint8_t better_calib_value;
	better_calib_value = eeprom_read_byte(0);
	if((better_calib_value != 0xFF) && (better_calib_value != 0x00))
	{
		OSCCAL = better_calib_value;
	}
	
	// Set PA0 as output
	DDRA |= _BV(PORTA0);
	
	// Set PA1 as input
	DDRA &= ~_BV(PORTA1);
	
	// Activate the PA1 pull-up resistor
	PORTA |= _BV(PORTA1);
	
	// Set PB2 to PB7 ports as output, and PB0 and PB1 as input
	DDRB = 0xFC;
	
	// Disable PB0 and PB1 pull-up resistors, so they can be used as Analog Inputs
	PORTB &= ~_BV(PORTB0) & ~_BV(PORTB1);
	
	// Set all PD ports as output
	DDRD = 0xFF;
	
	// Enable Analog Comparator Input Capture
	ACSR |= _BV(ACIC);
	
	// Select Analog Comparator Interrupt on Rising Output Edge
	//ACSR |= _BV(ACIS1) | _BV(ACIS0); //Not needed if I use the Timer/Counter1 Input Capture interrupt
	
	// Enable Analog Comparator Interrupt
	//ACSR |= _BV(ACIE); //Not needed if I use the Timer/Counter1 Input Capture interrupt
	
	// Select clkio/1024 as Timer/Counter0 clock source
	/* With the CPU running at 8 MHz, this will result in timer overflow at ~30.5 Hz rate.
	Don't need to update the display more frequently than this. */
	TCCR0B |= _BV(CS00) | _BV(CS02);
	
	// Enable Timer/Counter0 Overflow interrupt
	TIMSK |= _BV(TOIE0);
	
	// Select Rising Edge for the Timer/Counter1 Input Capture
	TCCR1B |= _BV(ICES1);
	
	// Enable filter for the Timer/Counter1 Input Capture
	//TCCR1B |= _BV(ICNC1); //Seems to work better without this
	
	// Select clkio/8 as Timer/Counter1 clock source
	/* Since the CPU is clocked at 8 MHz, the timer will increment at 1 MHz.
	This means every tick is 1 microsecond, and the timer will overflow
	about every 65536 microseconds, or ~15.23 Hz.
	This is lower than note C0, which is 16.35 Hz */
	TCCR1B |= _BV(CS11);
	
	// Enable Timer/Counter1 Input Capture interrupt
	TIMSK |= _BV(ICIE1);
}

/*
Handle Timer0 overflow interrupt, which basically delivers the
number of microseconds counted by Timer1 to the calculate_note function,
as long as the Tuner Switch is on.
*/
ISR(TIMER0_OVF_vect)
{
	uint16_t buffered_timestamp = 0;
	
	sei(); //To allow nested interrupt handling, since Timer1 events are more frequent
	
	if(OnOff_SWITCH_STATUS)
	{
		// Buffer the event timestamp
		buffered_timestamp = event_timestamp;
		
		// Calculate note to be displayed
		calculate_note(buffered_timestamp);	
	}
	else
	{
		// Switch off all display segments
		ALL_SEGS_OFF();
		
		// Switch off all LEDs
		ALL_LEDS_OFF();
	}
	
}

/*
Handle Timer1 event capture interrupt.
This interrupt is raised when the Analog Comparator output transitions
from low to hight, which is detected by the Timer1 event capture block.
This means Timer1 detects when a new wave cycle starts, and should reset
itself immediately in order to start counting the period of the next
wave cycle.
*/
ISR(TIMER1_CAPT_vect)
{
	// Reset Timer1 immediately
	TCNT1 = 0x0000;

	// Check if Timer1 overflowed, which means the measured period is too long
	if(TIFR & _BV(TOV1))
	{
		// Toggle the DP segment to indicate overflow has occurred
		PINA |= _BV(PINA0);
		
		// Force frequency calculation to result in 15.26 Hz (lower than C0)
		event_timestamp = 0xFFFF;
		
		// Reset Timer1 overflow flag
		TIFR |= _BV(TOV1);
	}
	else
	{
		// Save event time stamp
		event_timestamp = ICR1;	
		
		// Make sure DP segment is off
		PORTA &= ~_BV(SEG_DP);
	}
}

/*
Main function
*/
int main(void)
{
	// Disable global interrupts
	cli();
	
	// Configure the uC
	ioinit();
	
	// Allow user to check the display and LEDs are working
	init_display();
	
	// Enable global interrupts to enable the timers
	sei();
	
	// Enter infinite loop and let timers interrupt handlers do their job
    while (1) 
    {

    }
}

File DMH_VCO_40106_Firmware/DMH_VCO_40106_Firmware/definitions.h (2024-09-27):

/*
 * definitions.h
 *
 * Created: 25/08/2024 21:45:47
 *  Author: Draycon
 */ 


#ifndef DEFINITIONS_H_
#define DEFINITIONS_H_


/* CPU Clock for the delay macros */

#define F_CPU 8000000UL


/* Pin functions */

#define SAW_IN			PORTB0
#define COMP_REF		PORTB1

#define LED_Sharp		PORTB2
#define LED_R_Red		PORTB3
#define LED_R_Yellow	PORTB4
#define LED_C_Green		PORTB5
#define LED_L_Yellow	PORTB6
#define LED_L_Red		PORTB7

#define LED_Sharp_ON()		PORTB |= _BV(LED_Sharp)
#define LED_Sharp_OFF()		PORTB &= ~_BV(LED_Sharp)

#define LED_R_Red_ON()		PORTB |= _BV(LED_R_Red)
#define LED_R_Red_OFF()		PORTB &= ~_BV(LED_R_Red)

#define LED_R_Yellow_ON()	PORTB |= _BV(LED_R_Yellow)
#define LED_R_Yellow_OFF()	PORTB &= ~_BV(LED_R_Yellow)

#define LED_C_Green_ON()	PORTB |= _BV(LED_C_Green)
#define LED_C_Green_OFF()	PORTB &= ~_BV(LED_C_Green)

#define LED_L_Yellow_ON()	PORTB |= _BV(LED_L_Yellow)
#define LED_L_Yellow_OFF()	PORTB &= ~_BV(LED_L_Yellow)

#define LED_L_Red_ON()		PORTB |= _BV(LED_L_Red)
#define LED_L_Red_OFF()		PORTB &= ~_BV(LED_L_Red)

#define ALL_LEDS_OFF()			PORTB &= 0x03
#define ALL_ACCURACY_LEDS_OFF()	PORTB &= 0x07
#define ALL_ACCURACY_LEDS_ON()	PORTB |= 0xF8

#define SEG_A	PORTD6
#define SEG_B	PORTD5
#define SEG_C	PORTD4
#define SEG_D	PORTD3
#define SEG_E	PORTD2
#define SEG_F	PORTD1
#define SEG_G	PORTD0
#define SEG_DP	PORTA0

#define ALL_SEGS_OFF()	PORTD = 0x00

#define OnOff_SWITCH()			PORTA1
#define OnOff_SWITCH_STATUS		(PINA & _BV(PINA1))

#define MOSI	PORTB5
#define MISO	PORTB6
#define SCK		PORTB7


/* Note names */

#define	NOTE_Cs	1
#define	NOTE_D	2
#define	NOTE_Ds	3
#define	NOTE_E	4
#define	NOTE_F	5
#define	NOTE_Fs	6
#define	NOTE_G	7
#define	NOTE_Gs	8
#define	NOTE_A	9
#define	NOTE_As	10
#define	NOTE_B	11
#define	NOTE_C	12
#define	NOTE_TOO_LOW	13
#define	NOTE_TOO_HIGH	14


#endif /* DEFINITIONS_H_ */

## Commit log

2024-06-27 Moved VCO mki to its own repo
    [Core.kicad_sch, DMH_VCO_40106_PANEL.kicad_pcb, DMH_VCO_40106_PANEL.kicad_sch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]
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2024-06-29 Generated VCO Panel Gerbers for test
    [DMH_VCO_40106_PANEL-B_Cu.gbl, DMH_VCO_40106_PANEL-B_Mask.gbs, DMH_VCO_40106_PANEL-B_Paste.gbp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]
2024-06-29 Re-generated VCO panel gerbers for test
    Applied modifications as per JLCPCB capabilities
    [DMH_VCO_40106_PANEL-B_Cu.gbl, DMH_VCO_40106_PANEL-B_Mask.gbs, DMH_VCO_40106_PANEL-B_Paste.gbp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]
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2024-07-07 Replaced power bus caps physical size
    [Power.kicad_sch]
2024-07-16 Marked components using temporary values
    [Core.kicad_sch]
2024-07-21 Updates from testing on breadboard
    - Removed Bus CV input, normalled it to V/oct input jack instead
    - Renamed Lin FM input to Exp FM In 2
    - Added annotations about temporary resistor/pot values
    - Added annotations about pots and trimpots pinout
    [Core.kicad_sch, DMH_VCO_40106_PANEL.kicad_pcb, DMH_VCO_40106_PANEL.kicad_sch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]
2024-07-22 Update Core.kicad_sch
    - Inverted PW Mod pot orientation.
    [Core.kicad_sch]
2024-07-27 Added Cermet 3296W fp to trimpots
    [Core.kicad_sch, Sine_Shaper.kicad_sch, Triangle_Shaper.kicad_sch]
2024-07-28 Changed Exp FM input attenuator circuitry
    Made it so that I can kill the modulation completely when the pot is all de way CCW.
    [Core.kicad_sch]
2024-07-29 Added inverting summer to CV intake
    Design not finished, needs testing and calibration
    [Core.kicad_sch]
2024-07-30 V/Oct tracking in progress
    [Core.kicad_sch]
2024-08-02 Updated exponentiator resistors and capacitors
    [Core.kicad_sch]
2024-08-03 Added trimpots for fine centering and range
    [Core.kicad_sch]
2024-08-03 Improved fine freq adjustment
    And tidied up the CV input summing section
    [Core.kicad_sch]
2024-08-03 Changed Fine Range trimpot strategy
    ... in order to allow for range adjustment from -/+13 to -/+0.5 semitones
    [Core.kicad_sch]
2024-08-04 Improved PWM part
    Made PWM totally killable with 100k "amt" pot.
    Added duty cycle range trimpot.
    Added duty cycle balancing trimpot.
    [Core.kicad_sch]
2024-08-04 Added thermistor to the centring trimpot line
    [Core.kicad_sch]
2024-08-06 Made U3 into TL074 instead of TL072
    [Core.kicad_sch, Power.kicad_sch, Sine_Shaper.kicad_sch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]
2024-08-06 Added not about 2.2uF cap
    [Triangle_Shaper.kicad_sch]
2024-08-08 Corrected capacitor value
    Should be 2.2nF, not 2.2uF
    [Triangle_Shaper.kicad_sch]
2024-08-09 Improved range of Coarse knob
    ... and allowed Centering knob to set C1=32,7Hz as root note with Coarse knob all the way CCW.
    ... and added 1kHz to Sine output.
    [Core.kicad_sch, Sine_Shaper.kicad_sch, Triangle_Shaper.kicad_sch]
2024-08-10 Replaced 2N3904 with BC548
    [Sine_Shaper.kicad_sch]
2024-08-10 Adjusted all output gains to 10Vpp
    ... and added buffer stages for Sawtooth Out and Triangle Out in order to avoid modifying Triangle and Sine wafeform characteristics when connecting Sawtooth Out and Triangle Out to other modules.
    [Core.kicad_sch, DMH_VCO_40106_PCB.kicad_sch, Sine_Shaper.kicad_sch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]
2024-08-10 Added sawtooth zero crossing pulse generator
    [Core.kicad_sch]
2024-08-10 Finished Sync input design
    [Core.kicad_sch]
2024-08-10 Placed power for U4
    [Power.kicad_sch]
2024-08-11 Added Sync and Bus CV switches
    [Inputs_and_Outputs.kicad_sch]
2024-08-11 Fixed bug on sync input circuit
    ... in order to keep the pulse generator quiet when no signal is connected to the sync input.
    [Core.kicad_sch]
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2024-08-11 Placed unconnected flags where missing
    [Tuner.kicad_sch]
2024-08-13 Updated Tuner
    - Changed uC to ATtiny4313
    - Added LEDs
    - Created "function" field and updated all jacks, switches and pots
    [Core.kicad_sch, Inputs_and_Outputs.kicad_sch, Sine_Shaper.kicad_sch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]
2024-08-15 Organized power part and added protection diodes
    [Power.kicad_sch]
2024-08-15 Prepared for backbone connections design
    [Inputs_and_Outputs.kicad_sch]
2024-08-16 Added normalled backbone connections
    [Inputs_and_Outputs.kicad_sch]
2024-08-16 Prepared Inputs/Outputs sheet to split in 2 PCBs
    [DMH_VCO_40106_PCB.kicad_sch, Inputs_and_Outputs.kicad_sch, Tuner.kicad_sch]
2024-08-16 Updated pot mounting hole sizes
    [DMH_VCO_40106_PANEL.kicad_pcb, DMH_VCO_40106_PANEL.kicad_sch]
2024-08-16 Fixed trimpot fp linking
    [Core.kicad_sch, Power.kicad_sch, Sine_Shaper.kicad_sch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]
2024-08-16 Updated pot mounting hole fps
    [DMH_VCO_40106_PANEL.kicad_pcb]
2024-08-16 Started main PCB design
    [DMH_VCO_40106_PCB.kicad_pcb, Inputs_and_Outputs.kicad_sch]
2024-08-18 Added panel hole references to main PCB
    [DMH_VCO_40106_PANEL.kicad_pcb, DMH_VCO_40106_PCB.kicad_pcb]
2024-08-18 Started positioning components on PCB
    Moving some input resistores from main PCB to Jacks PCB
    [Core.kicad_sch, DMH_VCO_40106_PCB.kicad_pcb, Inputs_and_Outputs.kicad_sch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]
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2024-08-22 Organized Square and Sine Shaper components
    Also re-annotated the TL074 ICs to improve the layout
    [Core.kicad_sch, DMH_VCO_40106_PCB.kicad_pcb, Power.kicad_sch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]
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2024-08-26 Corrected RD90 pots pin 1 and 3 connections
    Otherwise all 6 pots would behave as if inverted
    [Core.kicad_sch, DMH_VCO_40106_PCB.kicad_pcb]
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2024-08-27 Removed the flat sign LED
    and rerouted segments A and B to PORTD 6 and 7 respective,
    and rerouted the DP segment to PORTA0
    [DMH_VCO_40106_PANEL.kicad_pcb, DMH_VCO_40106_PANEL.kicad_sch, DMH_VCO_40106_PCB.kicad_pcb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]
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2024-08-28 Placed input and output resistors back in main PCB
    This ensures a more clear schematic and leaves the Connectors PCB only with actual connectors.
    [Core.kicad_sch, DMH_VCO_40106_PCB.kicad_pcb, DMH_VCO_40106_PCB_Connectors.kicad_pcb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]
2024-08-31 Connected tuner switch to uC GPIO pin
    ... and all LED and display segments directly to GND
    [DMH_VCO_40106_PCB.kicad_pcb, Tuner.kicad_sch]
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2024-09-04 Replaced display seg calculation with direct value
    [main.c]
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2024-09-14 Fixed mistake with too low note segment pattern
    ... and added default case for diagnostics
    [main.c]
2024-09-14 FW work in progress
    Code left in state where fixed frequency point (e.g. 300Hz) is recognized, and the tuner swings from TOO LOW to TOO HIGH depending if below or above this frequency. I see a ~+10Hz offset though if checking the frequency in ableton. Also had to connect uc to square wave. Saw wave is too unstable without hysteresis.
    [Core.kicad_sch, DMH_VCO_40106_PCB.kicad_sch, Tuner.kicad_sch]
2024-09-15 Updated PCB with rerouting of square wave to tuner
    [DMH_VCO_40106_PCB.kicad_pcb]
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2024-09-15 Working state but with freq offset issue
    [definitions.h, main.c]
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2024-09-16 Replaced JLCJLCJLCJLC with space for serial number
    [DMH_VCO_40106_PANEL-B_Cu.gbl, DMH_VCO_40106_PANEL-B_Mask.gbs, DMH_VCO_40106_PANEL-B_Paste.gbp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]
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2024-10-01 Fixed resistor values and regenerated gerbers
    New gerbers version: Mk1.2
    Includes fix with small font problem with the # sign under the blue LED on the front panel.
    [Core.kicad_sch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]
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2025-01-02 Added info about jumpers to main PCB schematic
    [Inputs_and_Outputs.kicad_sch]
2025-01-02 Added GND to J200
    ... which means J2, J3 and J4 connections had to change pins.
    [Inputs_and_Outputs.kicad_sch]
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
